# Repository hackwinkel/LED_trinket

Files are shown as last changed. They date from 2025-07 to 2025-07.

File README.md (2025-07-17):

# trinket

The "trinket" is an electronic gimmick that reacts to the presence of other "trinket"s in the area, and contains a small flashlight.

It was conceived as a demonstration project and target for workshops.

## Folders

* 3D - contains 3D design files (SCAD) for the housing + a soldering aid

* Hardware - contains the schematic and PCB design files

* Workshop - Assembly instructions to go with the trinket soldering workshop

* Software - Firmware for the trinket

## Mixed soldering techniques workshop

The workshop around this badge teaches mixed Surface Mounted Device (SMD) soldering techniques. One side of the Printed circuit board is assembled using a stencil. solder paste and a hotplate for reflowing, the other side is manually populated. In addition there are a few Through-Hole components

## Low voltage or "flat battery" power supply

This trinket contains a boost converter to boost the (nominally 1.5V alkaline battery supply to 5V. This boost converter will start working at battery voltages above ~ 0.9V, but will also keep working until the battery voltage drops below ~ 0.7 V. This is well below the voltages at which alkaline batteries are normally considered empty.

WARNING: empty batteries can leak. Remove empty batteries. This is especially important for this circuit as it was designed to drain batteries as far as it can.

## Infrared communication
This trinket uses IR transmitters and receivers for inter-trinket communications. It uses the well known KISS protocol and should be compatible with other devices using this protocol.

## Flashlight mode
after a button press, 4 white leds light up.

## Blinking lights
When the trinket does not detect a fellow trinket in the neighborhood, it will slowly flash a white light. When another trinket is detected, it displays a pattern of colours.

## ultra low cost microcontrollers
The trinket contains a PADAUK PFS154-S16 microcontroller. The software/hardware *may* also work with a PMS150C-S16 and pin compatible controllers from other manufacturers (e.g. Nyquest tech), but this is untested.

## Programming prerequisites & instructions

You will need a PADAUK programmer to program the device. PADAUK microcontrollers use a proprietary programming algorithm.

Hardware and software for an open source programmer can be found here: https://github.com/free-pdk/easy-pdk-programmer-hardware and https://github.com/free-pdk/easy-pdk-programmer-software.

Follow the instructions provided on these pages.

To compile the software for the label you need:

1. Small Device C Compiler (SDCC) (https://sdcc.sourceforge.net/) version >=4

2. pdk-includes (https://github.com/free-pdk/pdk-includes)

3. easy-pdk-includes (https://github.com/free-pdk/pdk-includes)

3. This repository

Install SDCC as per instructions for your system

Make a containing directory to hold both this repository and the free-pdk  pdk-includes and easy-pdk-includes repositories and:

cd <your_dir>

git clone https://github.com/free-pdk/pdk-includes

git clone https://github.com/free-pdk/easy-pdk-includes

git clone https://github.com/hackwinkel/tag-software

cd tag-software

cd standard

make

make burn

This last command requires easypdkprog to be found in your $PATH. You can also run this command manually

Other make targets are: sizes (displays the sizes of various memory segments in the binary), clean and all (the default).

## alternative firmware

If you want to do something special with your trinket, please do so in an intelligent way, in an IR transmitting envelope that will NOT annoyingly interfere with other badges in your neighborhood:

1. Transmit IR codes once per minute at most

2. Transmit IR codes for one second at most

3. While not transmitting, listen for incoming IR signals, and act accordingly

Note: The PCB design does NOT support in-circuit reprogramming.

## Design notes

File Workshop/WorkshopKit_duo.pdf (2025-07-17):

# 13.37 HAX trinket soldering kit (duo)

Welcome to the 13.37 HAX trinket soldering workshop.

During this workshop you will gain some experience soldering various electronic parts on a small Printed Circuit Board (PCB) using different techniques. End product is a “trinket” – a small gimmick. This trinket has a few functions: It serves as a flashlight, you can write your name on it and wear it on a lanyard as a badge, and can detect the presence of other trinkets around it.

This kit contains the electronic parts for two trinkets. Please open the bag and check and get
familiar with its contents. If parts are packaged in a strip, please do not take them out yet.
Some parts are Surface Mounted Devices (SMD) without leads that go through holes in the PCB, other parts are Through Hole (TH) devices
type | nr | What | Identification | Front/Back
1 | 2 | PCBs | Green, BACK SIDE with text “hackwinkel. nl” | n.a.
2 | 4 | MOSFETs | 3 pin devices, 4 in black plastic strip | SMD F
3 | 2 | boost convertors | 3 pin devices, 2 in black plastic strip | SMD F
4 | 2 | diodes | 2 pin black devices, 2 in black plastic strip | SMD F
5 | 4 | IR transmitters | 2 pin white devices, 2 in black plastic strip | SMD F + B
6 | 4 | RGB LEDs | 6 pin white devices, 4 in black plastic strip | SMD F + B
7 | 2 | Inductors | 470, 2 in white plastic strip | SMD F
8 | 2 | capacitors | Brown, “small”, 2 in transparent plastic strip | SMD F
9 | 2 | capacitors | Brown, “large|”. 2 in transparent plastic strip | SMD F
10 | 4 | resistors | 3301, “small”, 4 in paper strip | SMD F
11 | 4 | resistors | 100, “large”, 4 in paper strip | SMD F + B
12 | 8 | resistors | 101, “small”, 8 in paper strip | SMD F
13 | 12 | resistors | 181, “small”. 12 in paper strip | SMD F + B
14 | 2 | microcontrollers | 16 pins, unpackaged | SMD F
15 | 2 | buttons | |”huge”, 4 pins, unpackaged | SMD B
16 | 4 | IR receivers | Black, 3 pins, unpackaged | TH F + B
17 | 8 | White LEDs | Transparent 2 pins, unpackaged | TH F + B
18 | 2 | Battery holder | Able to hold a AA cell | F

When you assemble an electronics kit, there is a preferred order in which to do this. In general this order is “from small height component to large height component” and “from centre of the PCB to the edge”. In this particular case, there are components on both sides of the PCB, which complicates matters a bit, plus, to make our life more enjoyable, we are going to use the “hotplate reflow soldering” technique for most parts.

When reflow soldering one does not use solder wire and a soldering iron, but instead of that solder paste and a means of heating the whole PCB to soldering temperature in one go. Solder paste is a mixture of small (20-49 um) balls of solder in a “flux” paste. It has the consistency of Nutella, but is gray and should not be consumed. Flux is a substance that will remove oxide layers when heated, allow the (then liquid solder) to flow nicely, and in the process will be converted into smoke. Solder wire also contains flux, for the same reasons.
We are going to use a stencil and a spatula to apply small dabs of solder paste to the contact pads on the PCB. How this is done will be demonstrated.

After the solder paste is applied to the front side of the PCB , we are going to place the components marked “SMD F” in the table above, in the order shown (part type 2 – 14). If parts are marked “SMD F + B” we are going to place half of the components, on the front side of the PCB only.

When placing parts we want to make sure that every metal contact of a part touches the correct
dab of solder paste. In some cases (MOSFETs and boost converters) the orientation of a part on the PCB is evident from the locations of the PCB contacts. In some cases (resistors, inductors and capacitors) orientation does not matter as long as metal contacts touch the solder paste. In some cases orientation is important. Mounting such parts in the wrong orientation may destroy them.

Place the front side SMD parts on the PCB with solder paste according to the table below:

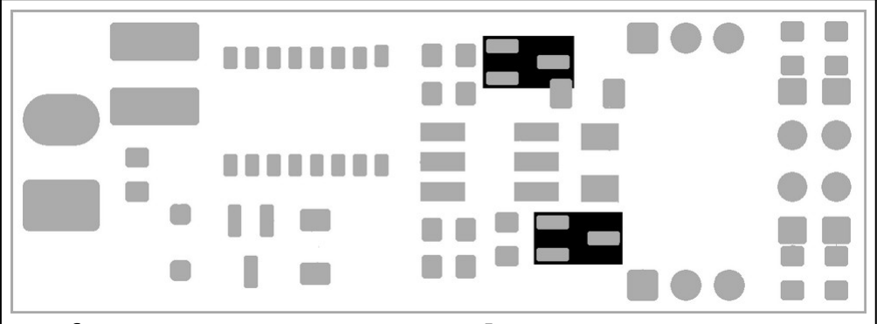
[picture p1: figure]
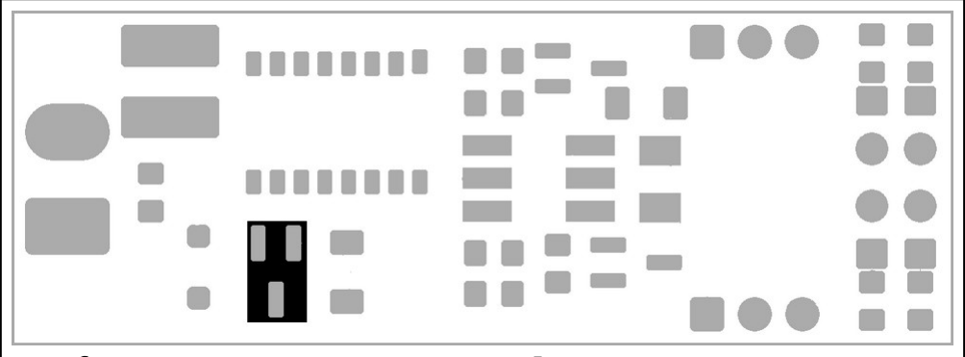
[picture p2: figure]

2 of type 2, orientation evident | 1 of type 3, orientation evident

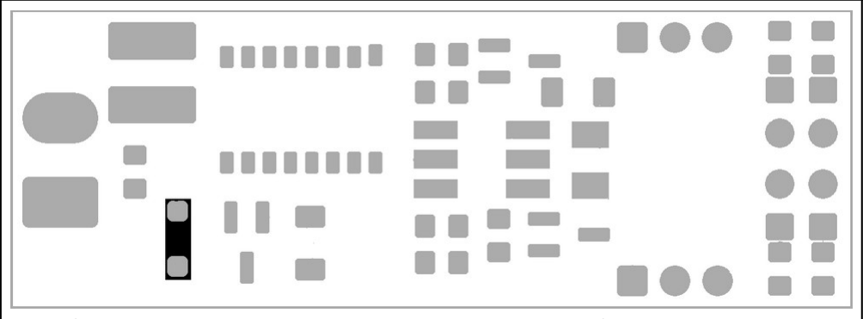
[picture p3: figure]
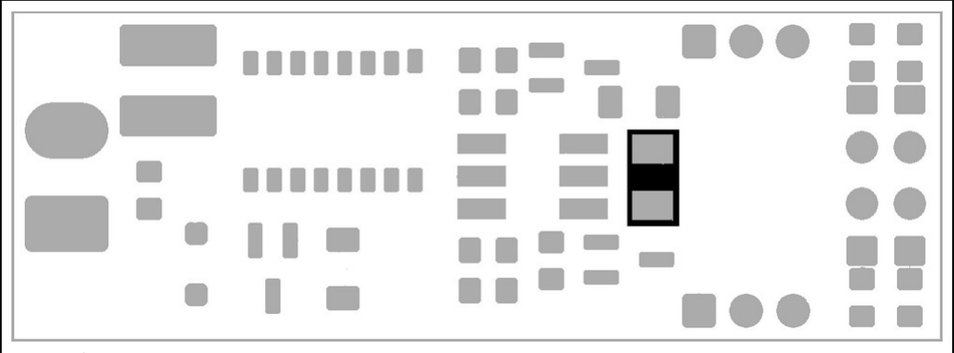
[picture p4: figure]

1 of type 4, lines toward bottom of image | 1 of type 5, larger pad towards bottom image

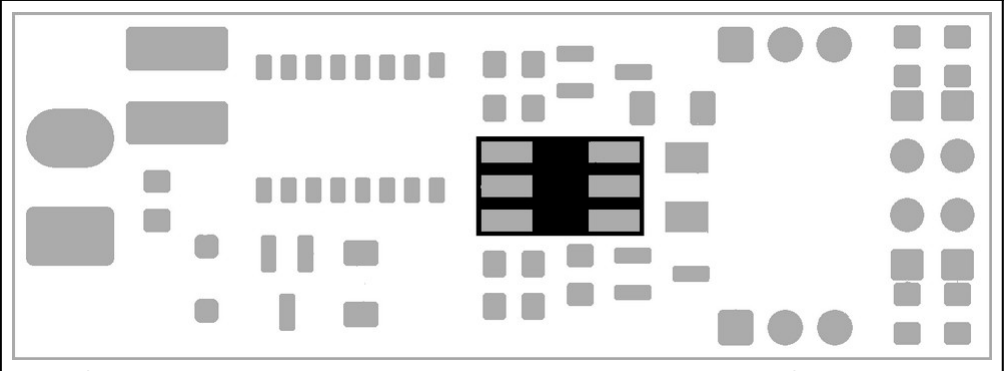
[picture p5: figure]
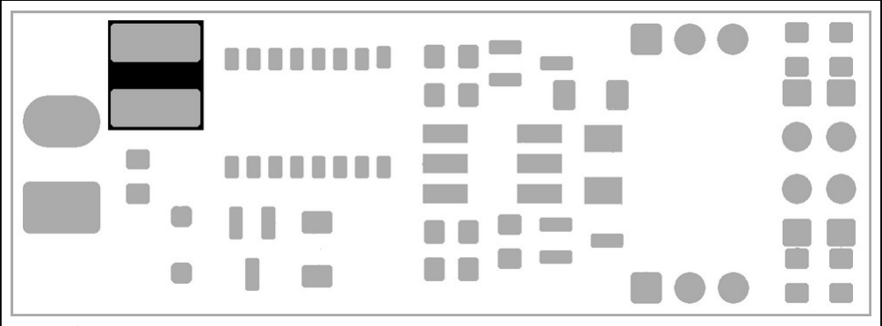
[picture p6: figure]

1 of type 6, “stick” like pad towards left | 1 of type 7, orientation not important

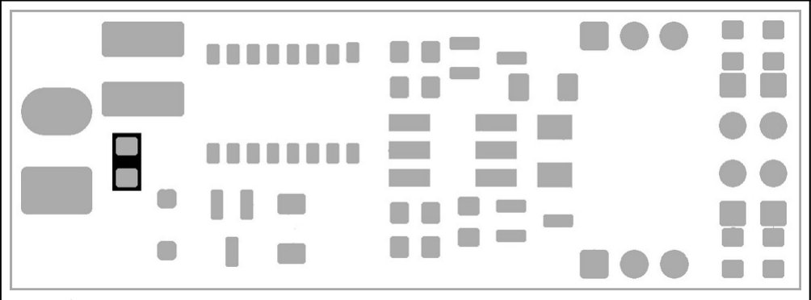
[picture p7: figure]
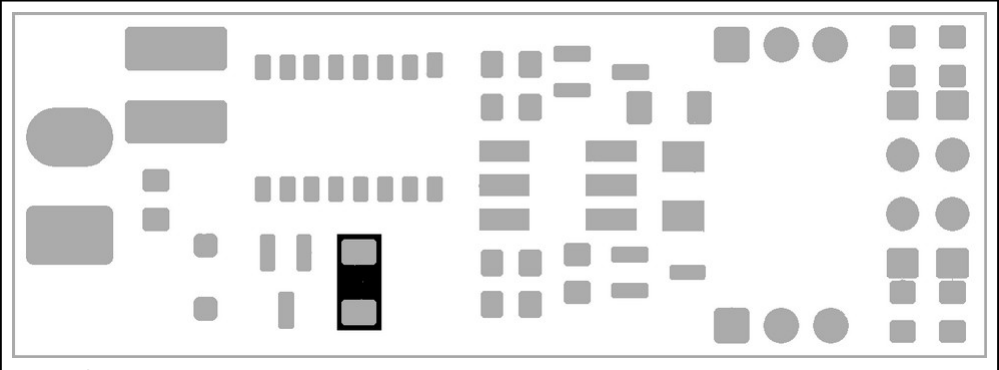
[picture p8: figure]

1 of type 8, orientation not important | 1 of type 9, orientation not important

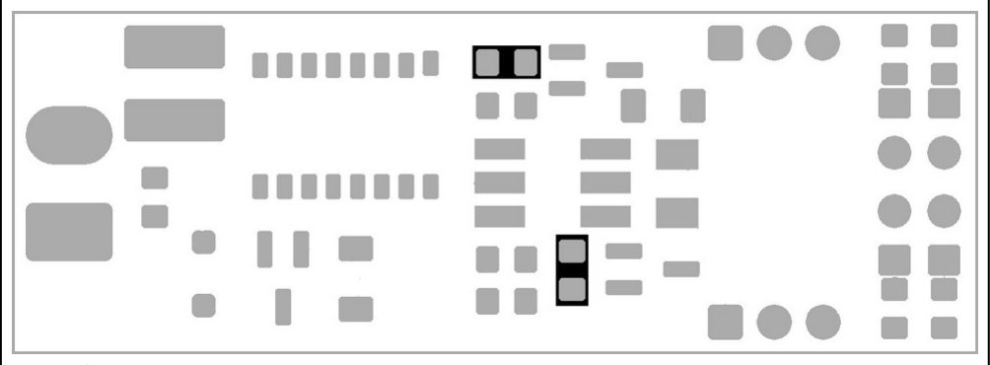
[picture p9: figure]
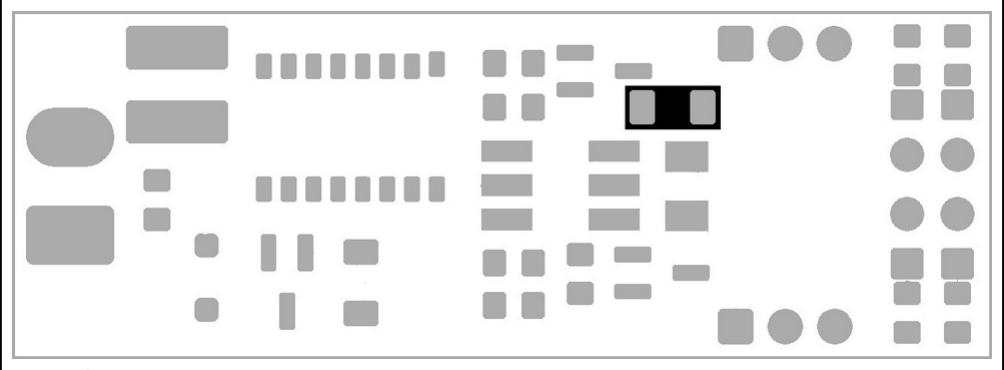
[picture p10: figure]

2 of type 10, black side up, orientation n.i. | 1 of type 11, black side up, orientation n.i.

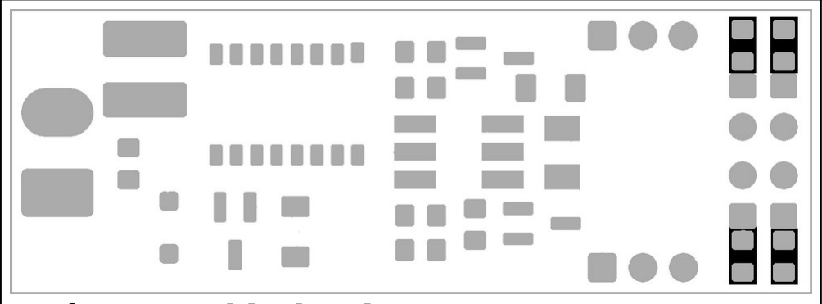
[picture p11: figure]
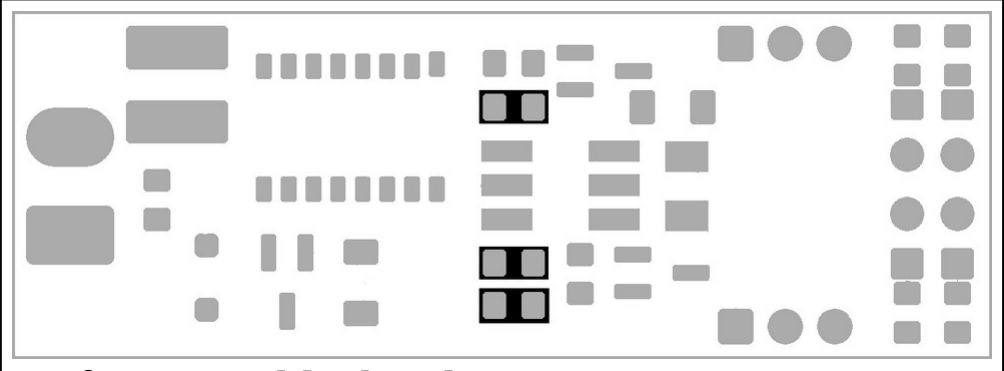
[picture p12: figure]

4 of type 12, black side up, orientation n.i. | 3 of type 13, black side up, orientation n.i.

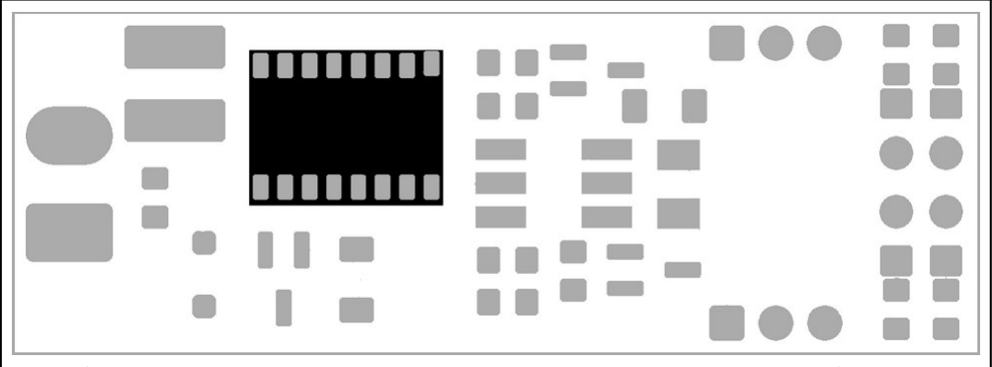
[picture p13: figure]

1 of type 14, dimple/dot towards centre of PCB

After placing al these parts, it is time to |reflow the solder using a hot plate. You will be instructed how to do this.

After the front side SMD parts have been soldered, it is time to turn our attention to the bottom side SMD parts. Of course these can’t be soldered using the same technique as one would have to place the PCB with parts on the front side, front-side down on the hotplate, melting the parts. We will sonder these parts manually.

Soldering SMD parts manually is easy with three or more hands. As we usually lack extra hands, we’ll make do with two plus an accessory: a PCB holder. Slip the PCB, components down, into the PCB holder, and place it on the table in front of you.
The following requires some confidence. You will NOT hurt yourself if you remain careful, and you will NOT destroy parts if you heat them a little longer. The biggest problem is people being ‘scared’ and removing the heat too quickly. Read this carefully, and if this is the first

### time you do this, do a practice-run of the moves without a soldering iron

To solder SMD components manually, we start by putting a small amount of fresh tin on one of the PCB pads for it. It is important that you tin only one of its PCB pads,because otherwise it will be nearly impossible to solder the part flat on the PCB. Next, you take the pad, ant put it in the correct orientation as close as possible next to the tinned pad, so you can push it in position using a nail or a toothpick once the tin is molten again.
Re-heat the pre-tinned pad, melting the tin, keep the soldering iron touching the tin while you push the part in position, then hold the part in position for a few seconds more while you remove the soldering iron. If you use your nails, then they may get hot. If you like this, use a toothpick. Try not to remove the soldering iron too quickly. While the solder is melted, you may align the part. After fixing the part to the PCB with one of its contacts in this way, solder the other contact(s) by touching the contact and pad at the same time for a second, then add a tiny bit of solder wire, remove the solder wire, then WAIT a second before removing the soldering iron. Repeat this until all the contacts of the part are soldered

The following SMD parts need to be soldered on the back side of the PCB in the given order.
1 of type 5 | Exactly on the opposite side of the PCB from the other IR transmitter. The larger pad needs to point in the opposite direction, and the arrow on the PCB points towards the smaller pad.
1 of type 6 | Exactly on the opposite side of the PCB from the other RGB LED. The “stick”-like pad needs to be away from the IR transmitter
1 of type 11 | On the two pads close to the IR transmitter, with black side up, orientation not important
3 of type 13 | On the remaining 3 locations for SMD resistors, in a similar arrangement as the other 3 resistors of this type on the front of the PCB
1 of type 15 | Orientation of the button is not important

Next up are the Through-hole parts.

We start with the IR receivers.The IR receivers have a (blind) flat side and a (sensitive) side with a bulge on it. If you put the IR receiver in front of you, with the back side on the table and the pins pointing towards you, the pins are numbered 1, 2 and 3 from left to right. Put the leads of one of the IR receivers through a row of three holes is such a way that pin 1 is in the hole with a square pad, AND in such a way that you can bend the IR receiver with the blind side towards the PCB. Bend the leads in such a way that the back side of the body of the IR receiver ends up in the square printed on the PCB. Solder the leads. Trim the leads using pliers, holding the lead you are cuttin to prevent them from catapulting away and hurting someone. Do the same, on the other side of the PCB, with the other IR receivers

Next are the LEDs If you look through the package material at the leads, you will see that one ends in a triangular “table” on which the (very small) ctual LED chip rests. The other pin is connected to the top of the LED-chip via a very thin wire. If you look at the PCB, you will see an array of 4 by 2 holes, some of which have a square pad, while others have a round pad. The square pads must be connected to the “table” pin, and the round pads must be connected to the other pin of the LEDs. The intention is to mount the leds at a right angle to the PCB, two on either side. The row of 4 holes right next to the edge of the PCB can serve LEDs on one side of the PCB, while the other row of 4 holes can serve the LEDs on the other side. The accessory has two holes and two |”barriers|” to help you bend the legs of the LEDS to the correct length for the “edge row” or “inner row” respectively. Bend and solder the “edge row” LEDs first, taking care to do so in the correct orientation, then trim the leads. Next bend and mount the “inner row” LEDs and trim back the leads.

Last is the battery holder: Solder the red wire to the oval pad and the black wire to the rectangular pad.

If no housing is available you can 3d-print one yourself, using a transparent material for the head, and any material for the body and button. Insert the PCB in the “head”, insert the battery holder in the “bottom”, carefully push body and head together, and insert the button cap through the hole.

# Operating manual

Insert a 1.5V alkaline AA battery. This can also be a battery that is considered “empty” by most other electronics – the trinket will start to run from less than 1V battery voltage, and continue (with reduced functionality) until the battery voltage drops below ~ 0.5V

Remove the battery when not in use. As this trinket really drains the battery, there is a high probability of battery leakage if the battery is left in.
A short button-press will switch on the flashlight. After a few seconds or after a second button-
press the flashlight will be switched off again.
A long button-press will switch on the flashlight. After about a minute or after a second button-
press the flashlight will be switched off again.

The trinket will detect other trinkets. When other trinkets are detected the RGB leds will show different colours. When no other trinkets are detected, it will emit short white flashes.

The trinket will announce its presence. Using short pulses of infrared light, about once a minute.

The KISS communication protocol of the trinket may be compatible with previous years’ projects: the tag and the label.

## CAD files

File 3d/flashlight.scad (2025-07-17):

# (c) 2025 Theo Borm
# See LICENSE FILE
module penliteholder() {
    translate([4,0,9.5]) rotate([0,90,0]) cylinder(50,7.5,7.5, $fn=100);
     translate([0,-8.5,0]) cube([58,17,13.5]);
}


module flashlightbody(d,h,c,t) {
    difference() {
        union() {
            intersection() {
                translate([-d/2,-d/2,0]) cube([d,d,h+d]);
                union() {
                    cylinder(h,d/sqrt(2)-c,d/sqrt(2)-c,$fn=100);
                    translate([0,0,h]) sphere(d/sqrt(2)-c,$fn=100);
                }
            }
            translate([-2.5,-d/2,h]) cube([5,d,d]);
            translate([-2.5,0,h+d]) rotate([0,90,0]) cylinder(5,d/2,d/2,$fn=100);
        }
        translate([-5,0,h+d]) rotate([0,90,0]) cylinder(10,4,4,$fn=50);
        intersection() {
            translate([t-d/2,t-d/2,-t]) cube([d-t-t,d-t-t,h+d]);
            translate([0,0,-t]) union() {
                cylinder(h,d/sqrt(2)-c-t,d/sqrt(2)-c-t,$fn=100);
                translate([0,0,h]) sphere(d/sqrt(2)-c-t,$fn=100);
            }
        }
        translate([0,0,8]) rotate([0,90,0]) cylinder(20,4,4,$fn=50);
    }
    translate([-d/2-0.01,-3.5,5]) rotate([0,-90,0]) linear_extrude(0.4) text("hackwinkel.nl",7, font="DejaVu Sans:style=Bold");
}


//w=wide part, n= narrow part d=diameter, h=height, o=offset, c=corner inset, t=thickness
module flashlighthead(dw,dn,hw,hn,c,t,tt) {
    difference() {
        
        // the outline consists of a neck and a head
        union() {
            //neck
            intersection() {
                translate([-dw/2,-dw/2,0]) cube([dw,dw,hw]);
                cylinder(hw,dw/sqrt(2)-c,dw/sqrt(2)-c,$fn=100);
            }
            // head
            intersection() {
                translate([-dn/2,-dn/2,0]) cube([dn,dn,hn]);
                cylinder(hn,dn/sqrt(2)-c,dn/sqrt(2)-c,$fn=100);
            }
        }
        
        //beveling around bottom
        rotate([0,0,0]) translate([0,dw/2-1,0]) rotate([-45,0,0]) translate([-50,0,-50]) cube([100,100,100]);
        rotate([0,0,90]) translate([0,dw/2-1,0]) rotate([-45,0,0]) translate([-50,0,-50]) cube([100,100,100]);
        rotate([0,0,180]) translate([0,dw/2-1,0]) rotate([-45,0,0]) translate([-50,0,-50]) cube([100,100,100]);
        rotate([0,0,270]) translate([0,dw/2-1,0]) rotate([-45,0,0]) translate([-50,0,-50]) cube([100,100,100]);
        rotate([0,0,45]) translate([0,dw/sqrt(2)-c-1,0]) rotate([-45,0,0]) translate([-50,0,-50]) cube([100,100,100]);
        rotate([0,0,135]) translate([0,dw/sqrt(2)-c-1,0]) rotate([-45,0,0]) translate([-50,0,-50]) cube([100,100,100]);
        rotate([0,0,225]) translate([0,dw/sqrt(2)-c-1,0]) rotate([-45,0,0]) translate([-50,0,-50]) cube([100,100,100]);
        rotate([0,0,315]) translate([0,dw/sqrt(2)-c-1,0]) rotate([-45,0,0]) translate([-50,0,-50]) cube([100,100,100]);
        
        // remove the core to create a tube, t=thickness
        translate([0,0,5]) intersection() {
            translate([t-dn/2,t-dn/2,0]) cube([dn-t-t,dn-t-t,hn+2]);
            cylinder(hn+2,dn/sqrt(2)-c-t,dn/sqrt(2)-c-t,$fn=100);
        }
        
        // make a section of the wide part thinner to make it translucent
        translate([0,0,5]) intersection() {
            translate([tt-dw/2,tt-dw/2,0]) cube([dw-tt-tt,dw-tt-tt,hw-10]);
            cylinder(hw-10,dw/sqrt(2)-c-tt,dw/sqrt(2)-c-tt,$fn=100);
        }
        
        
        //button hole in the middle pf the neck part 
        translate([0,0,hw+(hn-hw)/2]) rotate([0,90,0]) cylinder(20,4,4,$fn=50);
        
        
        //drill-through holes for white 5mm LEDs
        translate([-3,-3,0.2]) cylinder(10,2.75,2.75,$fn=50);
        translate([3,-3,0.2]) cylinder(10,2.75,2.75,$fn=50);
        translate([-3,3,0.2]) cylinder(10,2.75,2.75,$fn=50);
        translate([3,3,0.2]) cylinder(10,2.75,2.75,$fn=50);
        
        translate([-3,-3,2.1]) cylinder(3,1,3.5,$fn=50);
        translate([3,-3,2.1]) cylinder(3,1,3.5,$fn=50);
        translate([-3,3,2.1]) cylinder(3,1,3.5,$fn=50);
        translate([3,3,2.1]) cylinder(3,1,3.5,$fn=50);
 
        //slit for the PCB
        translate([-1,-(dw-tt-tt)/2,5]) cube([2,dw-tt-tt,100]);
    }
}

/*
module button() {
    difference()
        intersection()
        translate([0,0,-4]) cylinder(10,0,20)
*/


// was 19.5, now 20mm wide
//for (i = [0:2]) {
//    for (j = [0:2]) {
        //translate([i*40,j*40,0])
            //flashlightbody(d,h,c,t)
            //flashlightbody(20,75,1.5,0.8);
//    }
//}
    
//


// part that slides into body = 1.7mm smaller than body. 
// body skin thickness= 0.8mm, 2*0.8=1.6mm, so 0.1mm for "fit"

// w=wide part, n= narrow part d=diameter, h=height, o=offset, c=corner inset, t=thickness
// flashlighthead(dw,dn,hw,hn,c,t,tt) {

// head 20mm wide, neck 18.2mm wide, head 42.5mm high, neck an extra 15mm
// thickness in the neck 1mm, thickness in the thin part 0.8mm
for (i = [0:2]) {
    for (j = [0:1]) {
        translate([i*40,j*40,0])
        flashlighthead(20,18.2,42.5,57.5,1.5,1,0.8);
    }
}

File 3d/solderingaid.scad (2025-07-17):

#(c)2025 Theo Borm
#see LICENSE file
difference() {
    cube([100,100,7]);
    translate([41,24.5,5.5]) cube([18,50.5,5]);
    translate([43,26,-1]) cube([14,47,10]);
    translate([41,25,-1]) cube([18,15,10]);
    translate([41,63,-1]) cube([10,7,10]);
    translate([-5,-5,2]) rotate([0,-7,0]) cube([110,110,100]);
    translate([105,105,2]) rotate([0,-7,180]) cube([110,110,100]);
    
    translate([47,7,-1]) cylinder(10,2.75,2.75,$fn=100);
    translate([53,7,-1]) cylinder(10,2.75,2.75,$fn=100);
    translate([47,13,-1]) cylinder(10,2.75,2.75,$fn=100);
    translate([53,13,-1]) cylinder(10,2.75,2.75,$fn=100);
}

translate([50,0,0]) cube([10,3.5,12.5]);
translate([40,0,0]) cube([10,3.5,10]);

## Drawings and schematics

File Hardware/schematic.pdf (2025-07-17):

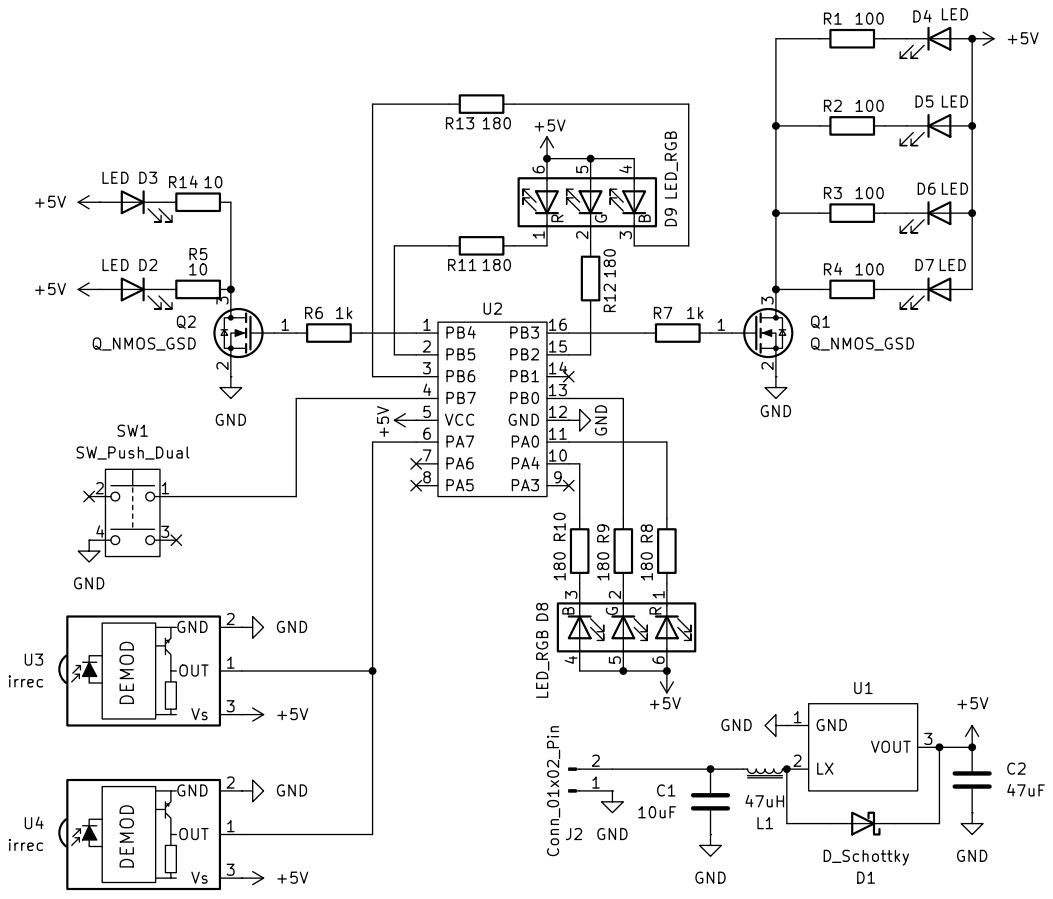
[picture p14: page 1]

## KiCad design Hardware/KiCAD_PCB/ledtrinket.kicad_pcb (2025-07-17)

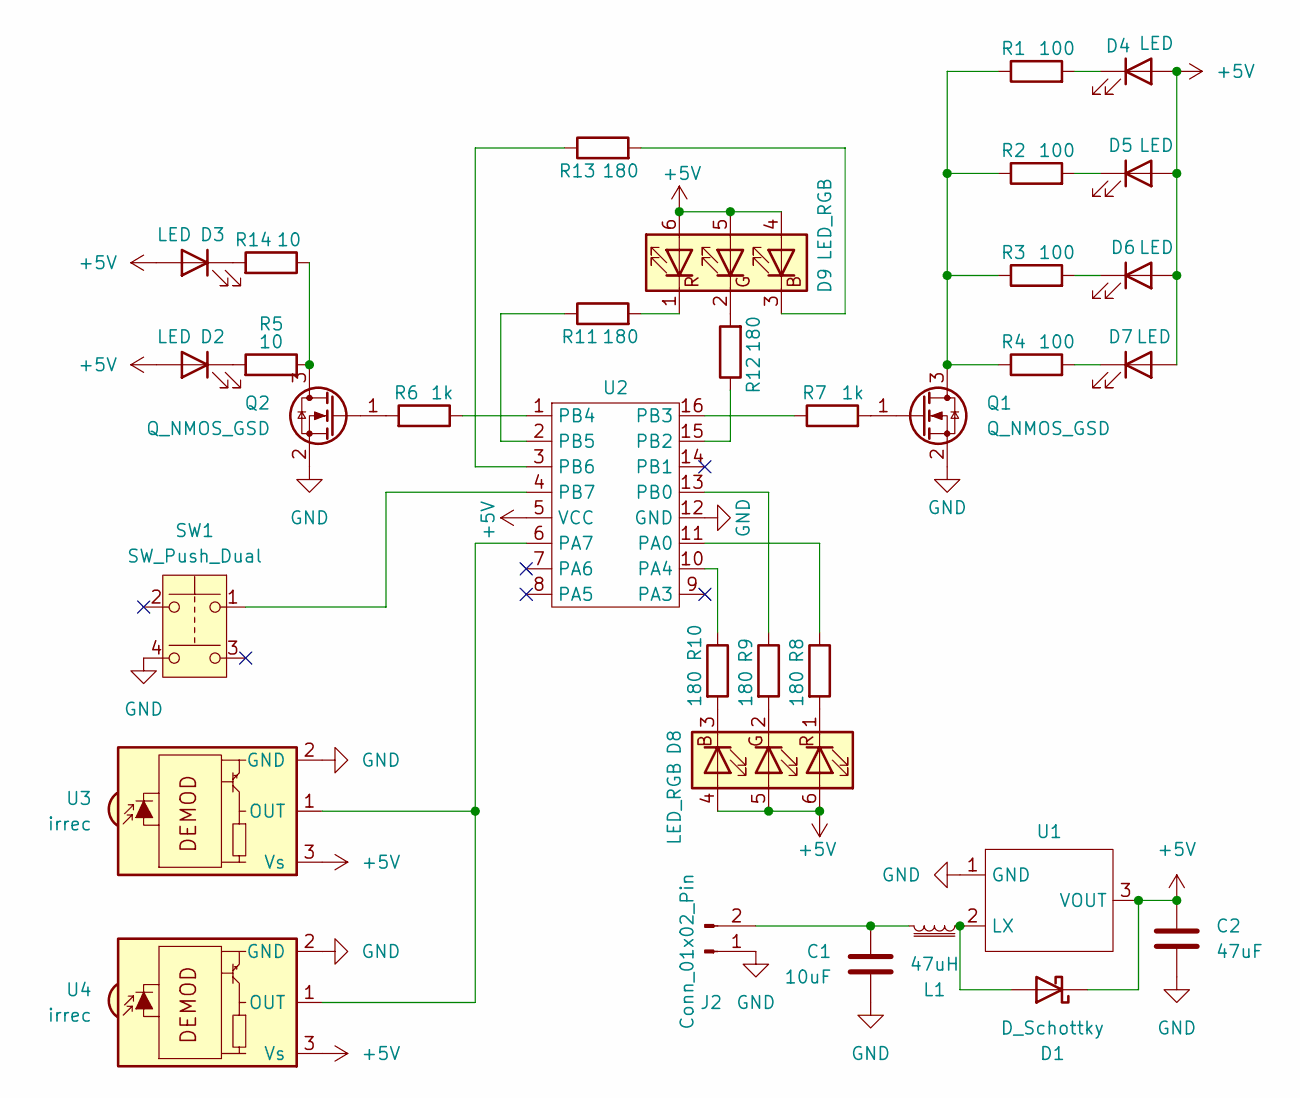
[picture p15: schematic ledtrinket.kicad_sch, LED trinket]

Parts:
C1: 10uF; C_0805
C2: 47uF; C_1206
D1: D_Schottky; D_SOD-123
D2, D3: LED; D_2835
D4, D5, D6, D7: LED; led_lamp_th
D8, D9: LED_RGB
J2: Conn_01x02_Pin; powpins
L1: 47uH; L
Q1, Q2: Q_NMOS_GSD; SOT-23
R1, R2, R3, R4: 100; R_0805
R5, R14: 10; R_1206
R6, R7: 1k; R_0805
R8, R9, R10, R11, R12, R13: 180; R_0805
SW1: SW_Push_Dual; button
U1: SOT-23
U2: SOP-16
U3, U4: irrec

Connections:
+5V: C2.1, D1.1 (K), D2.2 (A), D3.2 (A), D4.2 (A), D5.2 (A), D6.2 (A), D7.2 (A), D8.4 (BA), D8.5 (GA), D8.6 (RA), D9.4 (BA), D9.5 (GA), D9.6 (RA), U1.3 (VOUT), U2.5 (VCC), U3.3 (Vs), U4.3 (Vs)
GND: C1.2, C2.2, J2.1, Q1.2 (S), Q2.2 (S), SW1.4, U1.1 (GND), U2.12 (GND), U3.2 (GND), U4.2 (GND)
unnamed: D1.2 (A), L1.1, U1.2 (LX)
unnamed: D2.1 (K), R5.2
unnamed: D3.1 (K), R14.2
unnamed: D4.1 (K), R1.2
unnamed: D5.1 (K), R2.2
unnamed: D6.1 (K), R3.2
unnamed: D7.1 (K), R4.2
unnamed: D8.3 (BK), R10.2
unnamed: D8.2 (GK), R9.2
unnamed: D8.1 (RK), R8.2
unnamed: D9.3 (BK), R13.2
unnamed: D9.2 (GK), R12.2
unnamed: D9.1 (RK), R11.2
unnamed: C1.1, J2.2, L1.2
unnamed: Q1.3 (D), R1.1, R2.1, R3.1, R4.1
unnamed: Q1.1 (G), R7.2
unnamed: Q2.3 (D), R5.1, R14.1
unnamed: Q2.1 (G), R6.2
unnamed: R8.1, U2.11 (PA0)
unnamed: R10.1, U2.10 (PA4)
unnamed: U2.6 (PA7), U3.1 (OUT), U4.1 (OUT)
unnamed: R9.1, U2.13 (PB0)
unnamed: R12.1, U2.15 (PB2)
unnamed: R7.1, U2.16 (PB3)
unnamed: R6.1, U2.1 (PB4)
unnamed: R11.1, U2.2 (PB5)
unnamed: R13.1, U2.3 (PB6)
unnamed: SW1.1, U2.4 (PB7)

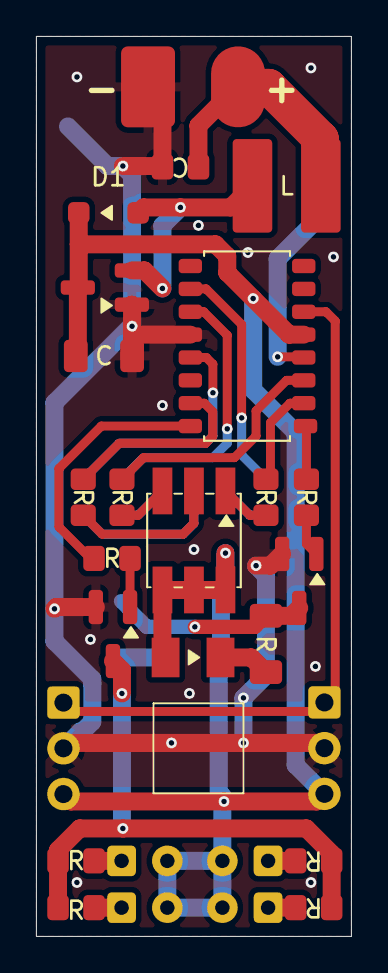
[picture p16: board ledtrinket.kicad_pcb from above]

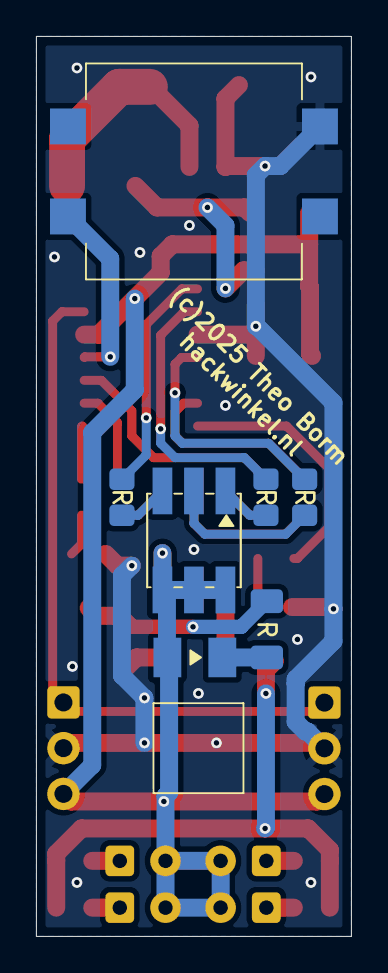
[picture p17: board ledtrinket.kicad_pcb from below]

Board: 2 copper layers, 17.5 x 50.0 mm, 34 parts (8 on the bottom side), 30 nets.

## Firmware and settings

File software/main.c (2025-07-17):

/*******************************************************************************
* (c) 2025 by Theo Borm
* see LICENSE file in this repository
*
* This firmware Controls the electronic "trinket"
*
* The trinket has two separate functions that have little in common:
* 1) It is a push-button operated flashlight
* 2) It communicates with other trinkets in the neighborhood, displaying a pallette
*    of colours when it detects others, and white flashes if it doesn't
*
* FLASHLIGHT
* the flashlight is operated by a push-button, operating a state machine.
* the state machine code is run 1000 times per second, so this statemachine
* also handles timing through a timeout counter
*
* fstate   | condition 		| action(s)
* start    |           		| OFF, fstate=0
* 0        | BUTTON    		| ON, fstate=1, timeout=2000
* 0        | nBUTTON   		|
*
* 1	   | BUTTON & nTIMEOUT	| timeout--
* 1	   | nBUTTON & nTIMEOUT | fstate=2, timeout=10000
* 1 	   | TIMEOUT            | fstate=5, timeout=50000
*
* 2        | nBUTTON & nTIMEOUT | timeout--
* 2	   | nBUTTON & TIMEOUT  | OFF, fstate=0
* 2	   | BUTTON		| fstate=3, OFF, timeout=500
*
* 3        | nTIMEOUT & BUTTON	| timeout--
* 3	   | TIMEOUT & BUTTON	| fstate=4, ON, timeout=500
* 3        | nBUTTON		| fstate=0
*
* 4	   | nTIMEOUT * BUTTON  | timeout--
* 4	   | TIMEOUT & BUTTON	| fstate=3, OFF, timeout=500
* 4	   | nBUTTON		| OFF, fstate=0
*
* 5	   | nTIMEOUT		| timeout--
* 5	   | TIMEOUT		| OFF, fstate=6, timeout=100
*
* 6	   | nTIMEOUT		| timeout--
* 6	   |  TIMEOUT		| ON, fstate=7, timeout=10000
*
* 7	   | BUTTON		| fstate=5, timeout=50000
* 7	   | nBUTTON & nTIMEOUT | timeout--
* 7        | nBUTTON & TIMEOUT  | OFF, fstate=0
*
* off -> short press -> on -> short press -> off
* off -> short press -> on -> long press -> blink -> release -> off
* off -> short press -> on -> 10s timeout -> off
* off -> long press -> on -> 50s timeout -> short blink -> 10s timeout -> off
* off -> long press -> on -> (*) 50s timeout -> short blink -> short press -> (*)
*
* TRINKET DETECTOR
*
* Trinkets detect each others presence through IR pulses they transmit about
* once a minute. Each pulse lasts a few ms, and modulates a38 kHz carrier.
* While a trinket is transmitting an IR pulses plus a few ms afterwards, reception
* of IR pulses is disabled so it does not react to itself.

* Trinkets can be in one of two states: "together" or "alone". When "alone", a
* trinket transmits a short (~16ms) white flash every ~2s on alternating RGB leds.
* When "together", a trinket slowly but continuously cycles through a range of
* colours, albeit at e alower intensity. The color patters and the together/alone
* handling are handled using two separate state machines. These state machines'
* code is run 1000 times per second and timing is handled through timeout counters
*
*<------ one synchronization cycle ------------>
*   +-----+
*   |     |
*---+     +------------------------------------- pulse from some trinket A - detected by other trinkets
*
*   +---------+
*   |         |
*---+         +--------------------------------- deaf time trinket A
*
*             +-----------+
*             |           |
*-----------=-+           +-------------------- register-pulse-but-don't-resync-time A
*
*---+                     +---------------------
*   |                     |
*   +---------------------+                      register AND resync time A
*
*phases trinket A
*
*00001111112222333333333333000000000000000000000
* 0: during this time pulses are registered AND used to resynchronize
* 1: during this time a pulse is transmitted and the tinket is deaf
* 2: during this time the trinket is still deaf
* 3: during this time the trinket registers pulses, but doesn't synchronize
*
*
phases trinket B (synchronizing with A)
00000044444411111122223333333333330000000000000
*   +-----+
*   |     |
*---+     +------------------------------------- received pulse from trinket A
^
*           +-----+
*           |     |
*-----------+     +----------------------------- pulse from atrinket B
*
* 4: during this time a trinket resynchronizes after receiving a pulse in phase 0
*
* ttimeout=0 means alone
*
* dstate   | condition 		   | action(s)
* start    |                       | pattern=0, dstate=0, dtimeout=60000
*
* any      | always at state-begin | dtimeout--, ttimeout-- (stop at 0), pattern++
*
* 0	   | nDTIMEOUT & nRECV     | 
* 0	   | nDTIMEOUT & RECV	   | dstate=4, ttimeout=65535 dtimeout=10
* 0	   | DTIMEOUT		   | dstate=1, dtimeout=10, ON
*
* 1	   | nDTIMEOUT		   | 
* 1        | DTIMEOUT		   | dstate=2, dtimeout=10, OFF
*
* 2        | nDTIMEOUT             | 
* 2        | DTIMEOUT              | dtimeout=20, dstate=3
*
* 3        | nDTIMEOUT & nRECV     | 
* 3	   | nDTIMEOUT & RECV	   | ttimeout=65535
* 3        | DTIMEOUT		   | dtimeout=60000, dstate=0
*
* 4        } nDTIMEOUT		   |
* 4        } DTIMEOUT              | dstate=1, dtimeout=10, ON
*
* if ttimeout == 0, then trinkets are unsynchronized, and the 16 bit pattern counter is
* used to generate short flashes of white light. counter bits: 
*               xxxx r100 0000 xxqq -> led r 15ms ON (after 1s, 5s, 9s, 13s, ....)
*               xxxx r100 0000 xxqq -> led r 15ms  ON (after 3s, 7s, 11s, 15s, ....)
*
* value of qq determines which constituent color LED may be on during that phase:
*	00	R1, G2
*	01	G1, B2
*	10	B1, R2
*	11	OFF
*
* if timeout !=0, then trinkets are "together", and the colour to display is derived
* from the 16 bit pattern counter which is set up to count from 0 to 6143:
*	counter value:		colour led 1	colour led 2
*	xxx0 000x xxxx xxxq     1,0,0		0,0,0
*	xxx0 001x xxxx xxxq     0,0,0		0,1,1
*	xxx0 010x xxxx xxxq     1,1,0		0,0,0
*	xxx0 011x xxxx xxxq     0,0,0		0,0,1
*	xxx0 100x xxxx xxxq     0,1,0		0,0,0
*	xxx0 101x xxxx xxxq     0,0,0		1,0,1
*	xxx0 110x xxxx xxxq     0,1,1		0,0,0
*	xxx0 111x xxxx xxxq     0,0,0		1,0,0
*	xxx1 000x xxxx xxxq     0,0,1		0,0,0
*	xxx1 001x xxxx xxxq     0,0,0		1,1,0
*	xxx1 010x xxxx xxxq     1,0,1		0,0,0
*	xxx1 011x xxxx xxxq     0,0,0		0,1,0
* the following patterns should never occur:
*	xxx1 100x xxxx xxxq     1,0,0		1,0,0
*	xxx1 101x xxxx xxxq     0,1,0		0,1,0
*	xxx1 110x xxxx xxxq     1,0,1		0,0,1
*	xxx1 111x xxxx xxxq     0,0,0		0,0,0
*
* note that at any one time at most two leds are "on" at the "same time"
* to halve the LED power consumption, a subphase q is used to quickly 
* switch between these two (at most) LEDs
*
* PFS154 pin assignment
* 
* pin	dir	func	active
* PA0	out	RGB1_R	low
* PA3	out	DEBUGIR	low
* PA4	out	RGB1_B	low
* PA5	n.c.	n.a.	n.a.
* PA6	n.c.	n.a.	n.a.
* PA7	in,p.u.	IR_IN	low
* PB0	out	RGB1_G	low	
* PB1	n.c.	n.a.	n.a.
* PB2	out	RGB2_G	low
* PB3	out	LIGHT	high
* PB4	out	IR_OUT	high
* PB5	out	RGB2_R	low
* PB6	out	RGB2_B	low
* PB7	in,p.u.	BUTTON	low
*/
/*
* PA3, PA5, PA6 and PB1 are used as debug status outputs
* PB1: 1Hz blinking from the main loop
* PA3: LOW when the trinket is transmitting an IR pulse
* PA6: LOW when the trinket is in the "long" flashlight state
*/






#include <stdint.h>
#include <device.h>
#include <calibrate.h>











/*******************************************************************************
* configure/calibrate system clock source
*/
unsigned char _sdcc_external_startup(void)
{
	// use the IHRC oscillator, target 4MHz
	PDK_SET_SYSCLOCK(SYSCLOCK_IHRC_4MHZ);
	// calibrate for 4MHz operation @ 3000 mVolt
	EASY_PDK_CALIBRATE_IHRC(4000000,3000);
	
	// watchdog is disabled by default
	
	
	/* MISC register bit settings
	 * 7: 0 reserved
	 * 6: 0 reserved
	 * 5: 1 FAST wake-up
	 * 4: 0 disable VDED/2 bias voltage generator
	 * 3: 0 reserved
	 * 2: 0 disable LVR
	 * 1: 0 WDT 8192
	 * 0: 0 WDT 8192
	 */
	 MISC=0x20;
	 
	return 0;   // keep SDCC happy
}



/*******************************************************************************
* NOTE: A large part (most) of the functionality is implemented in an interrupt.
*/


/******************************************************************************* 
* Global variables and definitions
*/

volatile uint8_t dstate; 	// the together/alone communication state machine
volatile uint16_t dtimeout; 	// the timeout counter for the detection states
volatile uint16_t ttimeout; 	// the timeout counter for the together/alone detection
volatile uint16_t pattern; 	// the pattern counter that determines what is shown on the RGB leds

volatile uint8_t fstate; 	// the state of the flashlight state machine
volatile uint16_t ftimeout; 	// the timeout counter for the flashlight

volatile uint8_t buttonshift;	// the state of the button as read from the pin during the last 8 cycles
volatile uint8_t buttonstate;	// the state of the button after debouncing
volatile uint8_t IRrecshift;	// the state of the IR receiver as read from the pin during the last 8 cycles
volatile uint8_t IRrecstate;	// the previous state & edge of the IR receiver after debouncing


uint8_t PA_next;		// variable used to compute next value for PA to prevent glitches
uint8_t PB_next;		// variable used to compute next value for PB to prevent glitches
#define R1_ON	PA_next &= 0x7e
#define G1_ON	PB_next &= 0x7e
#define B1_ON	PA_next &= 0x6f
#define R2_ON	PB_next &= 0x5f
#define G2_ON	PB_next &= 0x7b
#define B2_ON	PB_next &= 0x3f

/******************************************************************************* 
* Timer interrupt setup
*
* T16 can be clocked from several sources, use a clock divider and can generate
* an interrupt when a certain bit (8..15) changes. If T16 is NOT clocked from
* SYSCLOCK and IHRC is enabled, then it can wake the CPU from sleep.
* We assume the IHRC is calibrated to 16MHz, then dividing by 64 will produce
* a 250 KHz input clock to T16. After 256 clock pulses bit 8 will toggle, which
* is almost once a millisecond. To make it exactly once a millisecond, we should
* preload T16 (which is an up-counter) with the value 6.
* 
*/

// configure timer
void setup_ticks() {
	T16M = (uint8_t)(T16M_CLK_IHRC | T16M_CLK_DIV64 | T16M_INTSRC_8BIT);
	T16C=6;
	INTEN |= INTEN_T16;
}



// interrupt service routine - does all the work
void interrupt(void) __interrupt(0)
{
	if (INTRQ & INTRQ_T16)
	{
		INTRQ &= ~INTRQ_T16; // Mark as processed
		T16C=134;

		// generic stuff that needs to be done every ms
		
		pattern++;
		if (pattern >= 6144) { pattern=0; }
		
		if (dtimeout) dtimeout--;
		if (ttimeout) ttimeout--;
		if (ftimeout) ftimeout--;
		
		// debounce the button
		buttonshift = buttonshift << 1;
		if (PB & 0x80) buttonshift |= 1;
		if (buttonshift==0xff) buttonstate=0;
		if (buttonshift==0x00) buttonstate=1;
		
		// debounce the IR receiver and detect edge
		IRrecshift = IRrecshift << 1;
		if (PA & 0x80) { IRrecshift |= 1; }
		if ((IRrecshift & 0x1f)==0x1f) { IRrecstate = (IRrecstate << 1) & 0x02; }
		if ((IRrecshift & 0x1f)==0x00) { IRrecstate = ((IRrecstate << 1) & 0x02) | 1; }
		// arriving here, IRrecstate can have one of 4 values:
		// 0: IR signal inactive - no change
		// 1: IR signal going active edge -> this requires action!
		// 2: IR signal going inactive edge
		// 3: IR signal active - no change 
		
		
		// handle the state machines
		switch (fstate) {
			case 0:
				if (buttonstate) {
					// switch flashlight on (by setting PB3 high), and all other leds off
					PA |= 0b00010001;	
					PB |= 0b01101101;	

					fstate=1;
					ftimeout=500;
				}
				break;
			case 1:
				if (buttonstate==0) {
					fstate=2;
					ftimeout+=9500;
				} else if (ftimeout==0) {
					fstate=5;
				}
				break;
			case 2:
				if (buttonstate==1) {
					fstate=3;
					// switch off the flashlight (by setting PB3 low)
					PB &=0x77;
					ftimeout=500;
				} else if (ftimeout==0) {
					// switch off the flashlight (by setting PB3 low)
					PB &=0x77;
					fstate=0;
				}
				break;
			case 3:
				if (buttonstate==0) {
					fstate=0;
				} else if (ftimeout==0) {
					fstate=4;
					// switch flashlight on (by setting PB3 high), and all other leds off
					PA |= 0b00010001;	
					PB |= 0b01101101;	
					ftimeout=500;
				}				
				break;
			case 4: if (buttonstate==0) {
					fstate=0;
					// switch off the flashlight (by setting PB3 low)
					PB &=0x77;
				} else if (ftimeout==0) {
					fstate=3;
					// switch off the flashlight (by setting PB3 low)
					PB &=0x77;
					ftimeout=500;
				}
				break;
			case 5:
				if (buttonstate==0) {
					PA &= 0x3f; // flashlight debug signal on
					fstate=6;
					ftimeout=50000;
				}
				break;
			case 6:
				if (buttonstate==1) {
					PA |= 0x40; // debug flashlight signal off
					fstate=3;
					// switch off the flashlight (by setting PB3 low)
					PB &=0x77;
					ftimeout=500;
				} else if (ftimeout==0) {
					PA |= 0x40; // debug flashlight signal off
					fstate=7;
					// switch off the flashlight (by setting PB3 low)
					PB &=0x77;
					ftimeout=100;
				}
				break;
			case 7:
				if (ftimeout==0) {
					fstate=8;
					// switch flashlight on (by setting PB3 high), and all other leds off
					PA |= 0b00010001;	
					PB |= 0b01101101;	
					ftimeout=2000;
				}
				break;
			case 8:
				if (buttonstate==1) {
					fstate=5;
				} else if (ftimeout==0) {
					fstate=0;
					// switch off the flashlight (by setting PB3 low)
					PB &=0x77;
				}
				break;	
		}
		
		
		/* we use timer 2 to generate a  38kHz sync pulse on PB4. These settings are necessary:
		* IHRC 16MHz, 16000000/422=37.914 KHz
		* TM2C [7:4]=0010 (select IHRC); [3:2]=11 (output on PB4); [1] = 0 (period mode); [0] = 0 (do not invert);
		* TM2S [7] = 0 (8 bit resolution); [6:5]=00 (prescaler 1); [4:0]=00000 (scaler 1);
		* TM2B [7:0] -> 211
		*/

		switch (dstate) {
			case 0: // waiting for sync or timeout
				if (dtimeout==0) {
					dstate=1;
					dtimeout=10;
					// start transmitting an IR pulse of 10ms
					PA &= 0x77; // debug IR signal
					TM2C=0; // stop timer
					TM2CT=0;
					TM2B=211;
					TM2S=0; // clear the counter
					TM2C=0b00101100; // go!
				} 
				else if (IRrecstate == 0x01) { // IR pulse received!
					dstate=4;
					ttimeout=65535;
					dtimeout=50; // wait until pulse complete and originator listening again: 50 ms
				}
				break;
			case 1: // transmitting sync
				if (dtimeout==0) {
					dstate=2;
					dtimeout=25; // completely deaf for 10 ms
					// stop transmitting the IR pulse	
					PA |= 0x08; // IR debug signal
					TM2C=0; 	// stop PWM
					PB &= 0x6f; 	// make sure IR LED is off
				}
				break;
			case 2: // completely deaf
				if (dtimeout==0) {
					dtimeout=100; // listening but not resyncing for 100 ms
					dstate=3; 
				}
				break;
			case 3: // listening but not resyncing
				if (dtimeout==0) {
					dtimeout=30000; 
					dstate=0;
				} else if (IRrecstate == 0x01) { // IR pulse received
					ttimeout=65535;
				}
				break;
			case 4:	// 50ms deaf after spontaneously received sync
				if (dtimeout==0) { 
					dstate=5;
					dtimeout=10;

					// start transmitting a 10ms IR pulse
					PA &= 0x77; // debug IR signal
					TM2C=0; // stop timer
					TM2CT=0;
					TM2B=211;
					TM2S=0; // clear the counter
					TM2C=0b00101100; // go!
				}
				break;
			case 5: // transmitting sync
				if (dtimeout==0) {
					dstate=6;
					dtimeout=75; // become completely deaf for 75 ms
					// stop transmitting the IR pulse
					PA |= 0x08; // debug IR signal
					TM2C=0; 	// stop PWM
					PB &= 0x6f; 	// make sure IR LED is off
				}
				break;	
			case 6: // completely deaf
				if (dtimeout==0) {
					dtimeout=30000; // listening but not resyncing for 100 ms
					dstate=0; 
				}
				break;

		}
		
		
		if ((PB & 0x08)==0) {// the flashlight is OFF
			// get the current state of the non-RGB-LED pins so we can compute the NEXT state without affecting any other output pins
			PA_next=(PA & 0x7F) | 0x11;
			PB_next=(PB & 0X7F) | 0x65;

			if (ttimeout) { // trinket is together
				uint8_t phase=(pattern>>9) & 0x0f;
				uint8_t subphase=pattern & 1;
				switch (phase)
				{
					case 0:
						if (subphase) { R1_ON;}
						break;
					case 1:
					
						if (subphase) { G2_ON; } else { B2_ON; }
						break;
					case 2:
						if (subphase) { R1_ON; } else { G1_ON; }
						break;
					case 3:
						if (subphase) { B2_ON; }
						break;
					case 4:
						if (subphase) { G1_ON; }
						break;
					case 5:
						if (subphase) { R2_ON; } else { B2_ON; }
						break;
					case 6:
						if (subphase) { G1_ON; } else { B1_ON; }
						break;
					case 7:
						if (subphase) { R2_ON; }
						break;
					case 8:
						if (subphase) { B1_ON; }
						break;
					case 9:
						if (subphase) { R2_ON; } else { G2_ON; }
						break;
					case 10:
						if (subphase) { R1_ON; } else { B1_ON; }
						break;
					case 11:
						if (subphase) { G2_ON; }
						break;
					default:
						//should never happen - off
						break;
				}
			} else { // trinket is alone 
				if ((pattern & 0x07f8)==0x0400) { // just blink RGB leds for 8 ms
					switch (pattern & 3) {
						case 0: R1_ON; G2_ON; break;
						case 1: G1_ON; B2_ON; break;
						case 2: B1_ON; R2_ON; break;
						case 3: break;
					}
				}
			}
			
			// implement the changes to the RGB leds, leaving the other outputs unaffected
			PA=PA_next;
			PB=PB_next;
		}
	}
}






/*******************************************************************************
* main program - consists of setup and ... nothing
*/
void main(void) {
	// Initialize hardware:
	//PA0-6 are ACTIVE LOW, so set them HIGH before making them outputs
	//PB0-2 & PB5-6 are ACTIVE LOW, so set them HIGH before making them outputs
	PA=0x7f;	
	PB=0x67;	
	
  	//ENABLE pull-ups on PA5, PA7, PB7, DISABLE on all other pins
	PAPH = 0xA0; // 10100000
	PBPH = 0x80; // 10000000
	
	// PA0-6 and PB0-6 are OUTPUTS
	PAC=0x7f;
	PBC=0x7f;
  	

	// initialize variables
	dstate=0; 	// the together/alone communication state machine
	ttimeout=0; 	// the timeout counter for the together/alone detection
	dtimeout=60000; // the timeout counter for detection states
	pattern=0; 	// the pattern counter that determines what is shown on the RGB leds

	fstate=0; 	// the state of the flashlight state machine
	ftimeout=0; 	// the timeout counter for the flashlight
	
	buttonshift=0xff; // the state of the button as read from the pin during the last 8 cycles
	buttonstate=0; // the state of the button after debouncing and inverting

	// setup and start the timer
	setup_ticks();
	INTRQ = 0;
	__engint();                     // Enable global interrupts
	
	
	
	/* we have nothing to do inside the while(1) loop as everything is basically handled in
	 * an interrupt, so we use __stopexe() to stop the processor until an interrupt occurs.
	 * So we are free to do some debugging. First thing is to toggle a LED on a spare pin
	 * once a second to have an indication that the processor is up and running AND that the
	 * interrupt actually happebs. So we count to 500 in the while(1) loop using ctr and invert
	 * the diagnostic LED pin B1 (which is normally not connected)
	 */
	 
	uint16_t ctr=0;
	
	while (1) {
		ctr++;
		if (ctr>=500) {
			PB=PB ^ 0x02; // PB1 is used
			ctr=0;
		}
		__stopexe(); // low power sleep until next timer interrupt
	}
}
